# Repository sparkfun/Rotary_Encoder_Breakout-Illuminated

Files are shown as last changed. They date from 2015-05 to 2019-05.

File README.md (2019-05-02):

SparkFun Rotary Encoder Breakout - Illuminated (RG/RGB)
=======================================================

SparkFun Rotary Encoder Breakout - Illuminated (RG/RGB)

[*SparkFun Rotary Encoder Breakout - Illuminated (RG/RGB) (BOB-11722)*](https://www.sparkfun.com/products/11722)

This is a clever little breakout board for both the RGB and R/G illuminated rotary encoders. 
On one side, it breaks out all of the RGB pins to standard, breadboard friendly, 0.1" headers. 
Turn it over and it has a footprint for the R/G version! 

Repository Contents
-------------------
* **/Firmware** - Example for the RGB and RG Rotary Encoders
* **/Hardware** - Eagle design files (.brd, .sch)
* **/Libraries** - Archived library of the PinChangeInt used for the example code

Documentation
--------------
* **[Installing an Arduino Library Guide](https://learn.sparkfun.com/tutorials/installing-an-arduino-library/all#manually-installing-a-library---windows)** - Basic information on how to install an Arduino library. You will need to manually install the PinChangeInt Arduino library.
* **[SparkFun Fritzing repo](https://github.com/sparkfun/Fritzing_Parts)** - Fritzing diagrams for SparkFun products.
* **[SparkFun 3D Model repo](https://github.com/sparkfun/3D_Models)** - 3D models of SparkFun products. 

Product Versions
----------------

Compatible with the following rotary encoders: 

* [COM-15141](https://www.sparkfun.com/products/15141) - RGB rotary encoder - illuminated; buttons and LEDs are common cathode
* [COM-15140](https://www.sparkfun.com/products/15140) - RG rotary encoder - illuminated, buttons and LEDs are common anode
* _[COM-10982 (retired)](https://www.sparkfun.com/products/10982) - RGB rotary encoder - illuminated; buttons and LEDs are common cathode_
* _[COM-10596 (retired)](https://www.sparkfun.com/products/10596) - RG rotary encoder - illuminated, buttons and LEDs are common anode_

License Information
-------------------
This product is _**open source**_! 

The **hardware** is released under [Creative Commons ShareAlike 4.0 International](https://creativecommons.org/licenses/by-sa/4.0/).

Please use, reuse, and modify these files as you see fit. Please maintain attribution to SparkFun Electronics and release anything derivative under the same license.

Distributed as-is; no warranty is given.

- Your friends at SparkFun.

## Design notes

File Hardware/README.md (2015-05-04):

SparkFun <PRODUCT NAME> Design Files
=====================================

The .sch and .brd files hare are Eagle CAD schematic and PCB design files from SparkFun Electronics.
A freeware version of Eagle can be found [here](http://www.cadsoftusa.com/download-eagle/freeware/). 

License
---------
This product is open source! 
The hardware is released under [Creative Commons ShareAlike 4.0 International](https://creativecommons.org/licenses/by-sa/4.0/).

Please use, reuse, and modify these files as you see fit. Please maintain attribution to SparkFun Electronics and release anything derivative under the same license.

Distributed as-is; no warranty is given.

- Your friends at SparkFun.

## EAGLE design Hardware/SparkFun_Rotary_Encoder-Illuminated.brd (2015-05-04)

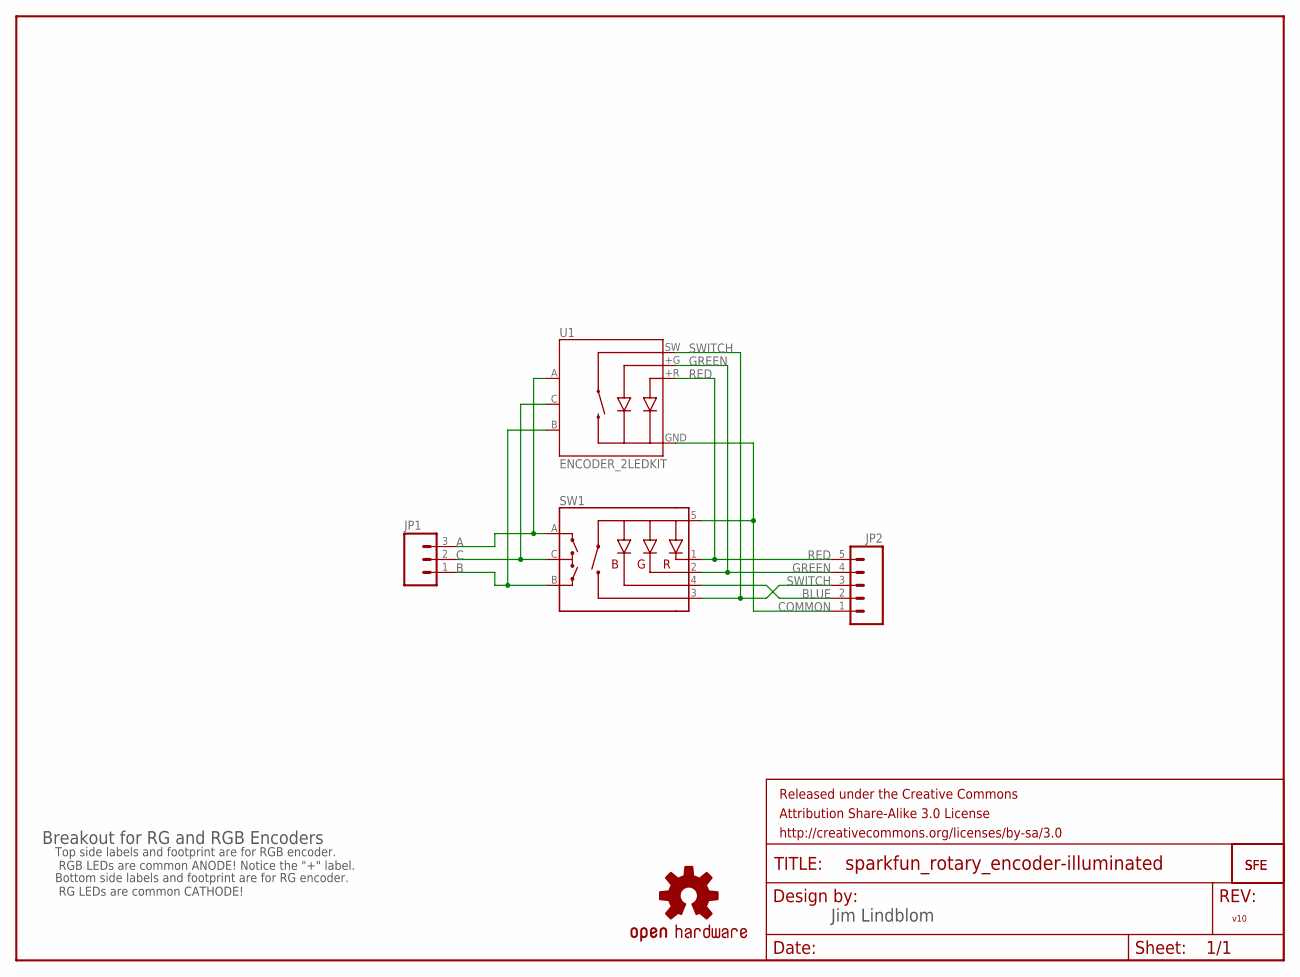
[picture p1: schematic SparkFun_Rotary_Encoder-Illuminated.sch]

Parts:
FRAME1: FRAME-LETTER; CREATIVE_COMMONS
JP1: M03PTH; 1X03
JP2: M05PTH; 1X05
JP3, JP4: LOGO-SFESK; SFE-LOGO-FLAME
SW1: ENCODER_RGB_CAKIT; ENCODER_LED_3_KIT
U1: ENCODER_2LEDKIT; ENCODER_LED_2_KIT
U$2: OSHW-LOGOS; OSHW-LOGO-S

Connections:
A: JP1.3, SW1.A, U1.A
B: JP1.1, SW1.B, U1.B
BLUE: JP2.2, SW1.4 (-B)
C: JP1.2, SW1.C, U1.C
COMMON: JP2.1, SW1.5 (+), U1.GND (-)
GREEN: JP2.4, SW1.2 (-G), U1.+G
RED: JP2.5, SW1.1 (-R), U1.+R
SWITCH: JP2.3, SW1.3 (SW), U1.SW

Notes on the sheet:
Jim Lindblom
Breakout for RG and RGB Encoders
Top side labels and footprint are for RGB encoder. RGB LEDs are common ANODE! Notice the "+" label.
Bottom side labels and footprint are for RG encoder. RG LEDs are common CATHODE!
v10

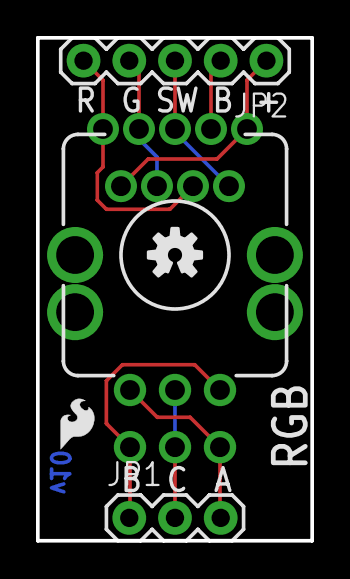
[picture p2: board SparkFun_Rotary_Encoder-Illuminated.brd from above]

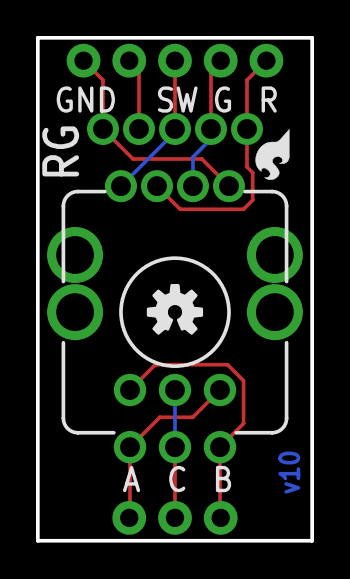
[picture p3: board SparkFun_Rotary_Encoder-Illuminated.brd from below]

Board: 2 copper layers, 15.2 x 27.9 mm, 9 parts (3 on the bottom side), 8 nets.

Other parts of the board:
U$1: OSHW-LOGOS; OSHW-LOGO-S

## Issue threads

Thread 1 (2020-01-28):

Rotary encoder demo code

NLoebel, 2020-01-28:
1.  Code uses syntax:   attachInterrupt(1, rotaryIRQ, CHANGE);

from https://www.arduino.cc/reference/en/language/functions/external-interrupts/attachinterrupt/ this doesn't necessarily work for different boards:

attachInterrupt(digitalPinToInterrupt(pin), ISR, mode) (recommended)
attachInterrupt(interrupt, ISR, mode) (not recommended)
attachInterrupt(pin, ISR, mode) (Not recommended. Additionally, this syntax only works on Arduino SAMD Boards, Uno WiFi Rev2, Due, and 101.)

2. Code uses:   attachInterrupt(1, rotaryIRQ, CHANGE);

although the code works as written (??), Pin 1 is not used in the sketch.  The rotary encoder is wired as:
(// Rotary encoder pin A to digital pin 3*     * Pins marked with an asterisk should not change
// Rotary encoder pin B to analog pin 3
// Rotary encoder pin C to ground

...so how this works attaching the interrupt to the wrong pin, I dunno.

3. Code states to attach LEDs directly to GPIO ports:

// Rotary encoder pin 1 (red anode) to digital pin 10
// Rotary encoder pin 2 (green anode) to analog pin 1
// Rotary encoder pin 3 (button) to digital pin 4

they should be attached through series dropping resistors to avoid high intensity one-shot flashes.

4. Code sets input pullups using deprecated syntax used prior to Arduino 1.0.1:

digitalWrite(ROT_A, HIGH); // turn on weak pullup

this should be replaced with pinMode(pin, INPUT_PULLUP); where pin is ROT_A, ROT_B

iceananas, 2020-02-21:
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

Both issues are related.
I agree about 1, this code is pretty old and still uses the old Arduino convention.

About 2. and why this code works, you find the answer in your own link:

> However, older sketches often have direct interrupt numbers. Often number 0 (for digital pin 2) or number 1 (for digital pin 3) were used.

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

Agree. This code could be updated.

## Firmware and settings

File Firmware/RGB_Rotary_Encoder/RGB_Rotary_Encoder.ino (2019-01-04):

// "RGB_Rotary_Encoder"
// Example sketch based on the Lilypad MP3 Player
// but modified for the the Arduino Uno/RedBoard
// Modified By: Ho Yun Bobby Chan
// By: Mike Grusin, SparkFun Electronics
// http://www.sparkfun.com

// This sketch demonstrates (only) the use of the rotary encoder
// hardware on the Lilypad MP3 Player board from Sparkfun. If you
// want to use the rotary encoder in your own sketches, this code
// will give you a starting point.

// HARDWARE CONNECTIONS

// This sketch will run on a LilyPad MP3 Player board (with
// a rotary encoder installed) without modifications.

// If you're not using the LilyPad MP3 Player board, connect
// a rotary encoder to your Arduino using these pins:

// Rotary encoder pin A to digital pin 3*
// Rotary encoder pin B to analog pin 3
// Rotary encoder pin C to ground

// This sketch implements software debounce, but you can further
// improve performance by placing 0.1uF capacitors between
// A and ground, and B and ground.

// If you wish to use the RGB LED and button functions of
// SparkFun part number COM-10982, use the following connections:

// Rotary encoder pin 1 (red cathode) to digital pin 10
// Rotary encoder pin 2 (green cathode) to analog pin 1
// Rotary encoder pin 3 (button) to digital pin 4
// Rotary encoder pin 4 (blue cathode) to digital pin 5
// Rotary encoder pin 5 (common anode) to VCC (3.3V or 5V)

// Note that because this is a common anode device,
// the pushbutton requires an external 1K-10K pullDOWN resistor
// to operate.

// * Pins marked with an asterisk should not change because
// they use interrupts on that pin. All other pins can change,
// see the constants below.

// SERIAL MONITOR

// Run this sketch with the serial monitor window set to 9600 baud.

// HOW IT WORKS

// The I/O pins used by the rotary encoder hardware are set up to
// automatically call interrupt functions (rotaryIRQ and buttonIRQ)
// each time the rotary encoder changes states.

// The rotaryIRQ function transparently maintains a counter that
// increments or decrements by one for each detent ("click") of
// the rotary encoder knob. This function also sets a flag
// (rotary_change) to true whenever the counter changes. You can
// check this flag in your main loop() code and perform an action
// when the knob is turned.

// The buttonIRQ function does the same thing for the pushbutton
// built into the rotary encoder knob. It will set flags for
// button_pressed and button_released that you can monitor in your
// main loop() code. There is also a variable for button_downtime
// which records how long the button was held down.

// There is also code in the main loop() that keeps track
// of whether the button is currently being held down and for
// how long. This is useful for "hold button down for five seconds
// to power off"-type situations, which cannot be handled by
// interrupts alone because no interrupts will be called until
// the button is actually released.

// Uses the PinChangeInt library by Lex Talionis,
// download from http://code.google.com/p/arduino-pinchangeint/

// License:
// We use the "beerware" license for our firmware. You can do
// ANYTHING you want with this code. If you like it, and we meet
// someday, you can, but are under no obligation to, buy me a
// (root) beer in return.

// Have fun!
// -your friends at SparkFun

// Revision history:
// 1.0 initial release MDG 2013/01/24

// Load the PinChangeInt (pin change interrupt) library

#include <PinChangeInt.h>

// LilyPad MP3 pin defines. Not all of these are used in this
// sketch; the unused pins are commented out:

#define ROT_LEDG A1     // green LED
#define ROT_B A3        // rotary B
#define ROT_A 3          // rotary A
#define ROT_SW 4         // rotary puhbutton
#define ROT_LEDB 5       // blue LED
#define ROT_LEDR 10      // red LED

// RGB LED colors (for common anode LED, 0 is on, 1 is off)
#define OFF B111
#define RED B110
#define GREEN B101
#define YELLOW B100
#define BLUE B011
#define PURPLE B010
#define CYAN B001
#define WHITE B000

// Global variables that can be changed in interrupt routines
volatile int rotary_counter = 0; // current "position" of rotary encoder (increments CW)
volatile boolean rotary_change = false; // will turn true if rotary_counter has changed
volatile boolean button_pressed = false; // will turn true if the button has been pushed
volatile boolean button_released = false; // will turn true if the button has been released (sets button_downtime)
volatile unsigned long button_downtime = 0L; // ms the button was pushed before release

// "Static" variables are initalized once the first time
// that loop runs, but they keep their values through
// successive loops.

static unsigned char x = 0; //LED color
static boolean button_down = false;
static unsigned long int button_down_start, button_down_time;

void setup()
{
  // Set up all the I/O pins. Unused pins are commented out.
  pinMode(ROT_B, INPUT);
  digitalWrite(ROT_B, HIGH); // turn on weak pullup
  pinMode(ROT_A, INPUT);
  digitalWrite(ROT_A, HIGH); // turn on weak pullup
  pinMode(ROT_SW, INPUT);
  // The rotary switch is common anode with external pulldown, do not turn on pullup
  pinMode(ROT_LEDB, OUTPUT);
  pinMode(ROT_LEDG, OUTPUT);
  pinMode(ROT_LEDR, OUTPUT);

  setLED(WHITE);

  Serial.begin(9600); // Use serial for debugging
  Serial.println("Begin RGB Rotary Encoder Testing");

  // We use the standard external interrupt pin for the rotary,
  // but we'll use the pin change interrupt library for the button.

  attachInterrupt(1, rotaryIRQ, CHANGE);
  PCintPort::attachInterrupt(ROT_SW, &buttonIRQ, CHANGE);
}

void buttonIRQ()
{
  // Process rotary encoder button presses and releases, including
  // debouncing (extra "presses" from noisy switch contacts).
  // If button is pressed, the button_pressed flag is set to true.
  // (Manually set this to false after handling the change.)
  // If button is released, the button_released flag is set to true,
  // and button_downtime will contain the duration of the button
  // press in ms. (Set this to false after handling the change.)

  // Raw information from PinChangeInt library:

  // Serial.print("pin: ");
  // Serial.print(PCintPort::arduinoPin);
  // Serial.print(" state: ");
  // Serial.println(PCintPort::pinState);

  static boolean button_state = false;
  static unsigned long start, end;

  if ((PCintPort::pinState == HIGH) && (button_state == false))
    // Button was up, but is currently being pressed down
  {
    // Discard button presses too close together (debounce)
    start = millis();
    if (start > (end + 10)) // 10ms debounce timer
    {
      button_state = true;
      button_pressed = true;
    }
  }
  else if ((PCintPort::pinState == LOW) && (button_state == true))
    // Button was down, but has just been released
  {
    // Discard button releases too close together (debounce)
    end = millis();
    if (end > (start + 10)) // 10ms debounce timer
    {
      button_state = false;
      button_released = true;
      button_downtime = end - start;
    }
  }
}


void rotaryIRQ()
{
  // Process input from the rotary encoder.
  // The rotary "position" is held in rotary_counter, increasing for CW rotation (changes by one per detent).
  // If the position changes, rotary_change will be set true. (You may manually set this to false after handling the change).

  // This function will automatically run when rotary encoder input A transitions in either direction (low to high or high to low)
  // By saving the state of the A and B pins through two interrupts, we'll determine the direction of rotation
  // int rotary_counter will be updated with the new value, and boolean rotary_change will be true if there was a value change
  // Based on concepts from Oleg at circuits@home (http://www.circuitsathome.com/mcu/rotary-encoder-interrupt-service-routine-for-avr-micros)
  // Unlike Oleg's original code, this code uses only one interrupt and has only two transition states;
  // it has less resolution but needs only one interrupt, is very smooth, and handles switchbounce well.

  static unsigned char rotary_state = 0; // current and previous encoder states

  rotary_state <<= 2;  // remember previous state
  rotary_state |= (digitalRead(ROT_A) | (digitalRead(ROT_B) << 1));  // mask in current state
  rotary_state &= 0x0F; // zero upper nybble

  //Serial.println(rotary_state,HEX);

  if (rotary_state == 0x09) // from 10 to 01, increment counter. Also try 0x06 if unreliable
  {
    rotary_counter++;
    rotary_change = true;
  }
  else if (rotary_state == 0x03) // from 00 to 11, decrement counter. Also try 0x0C if unreliable
  {
    rotary_counter--;
    rotary_change = true;
  }
}


void loop()
{
  // The rotary IRQ sets the flag rotary_counter to true
  // if the knob position has changed. We can use this flag
  // to do something in the main loop() each time there's
  // a change. We'll clear this flag when we're done, so
  // that we'll only do this if() once for each change.

  if (rotary_change)
  {
    Serial.print("rotary: ");
    Serial.println(rotary_counter, DEC);
    rotary_change = false; // Clear flag

    //blink for visual feedback
    setLED(OFF);
    delay(10); //try not to make this too long, otherwise the Arduino will miss ticks
    setLED(x);
  }

  // The button IRQ also sets flags to true, one for
  // button_pressed, one for button_released. Like the rotary
  // flag, we'll clear these when we're done handling them.

  if (button_pressed)
  {
    Serial.println("button press");
    //x++; setLED(x); // Change the color of the knob LED
    button_pressed = false; // Clear flag

    // We'll set another flag saying the button is now down
    // this is so we can keep track of how long the button
    // is being held down. (We can't do this in interrupts,
    // because the button state is not changing).

    button_down = true;
    button_down_start = millis();
  }

  if (button_released)
  {
    Serial.print("button release, downtime: ");
    Serial.println(button_downtime, DEC);
    x++; setLED(x); // Change the color of the knob LED
    button_released = false; // Clear flag

    // Clear our button-being-held-down flag
    button_down = false;

    //blink when you release the button press
    for (int i = 0; i < 4; i++) {
      digitalWrite(ROT_LEDR, LOW);
      digitalWrite(ROT_LEDG, HIGH);
      digitalWrite(ROT_LEDB, HIGH);
      delay(50);
      digitalWrite(ROT_LEDR, HIGH);
      digitalWrite(ROT_LEDG, HIGH);
      digitalWrite(ROT_LEDB, HIGH);
      delay(50);
    }

    setLED(x); // Change the color back to original color
  }

  // Now we can keep track of how long the button is being
  // held down, and perform actions based on that time.
  // This is useful for "hold down for five seconds to power off"
  // -type functions.

  if (button_down)
  {
    button_down_time = millis() - button_down_start;
    // Serial.println(button_down_time);
    if (button_down_time > 1000) {
      Serial.println("button held down for one second");
    }
    //if LED is pressed down, display red
    digitalWrite(ROT_LEDR, LOW);
    digitalWrite(ROT_LEDG, HIGH);
    digitalWrite(ROT_LEDB, HIGH);

  }
}


void setLED(unsigned char color)
// Set RGB LED to one of eight colors (see #defines above)
{
  digitalWrite(ROT_LEDR, color & B001);
  digitalWrite(ROT_LEDG, color & B010);
  digitalWrite(ROT_LEDB, color & B100);
}

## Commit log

2015-05-04 Adding README info, updating product files
    [SparkFun_Rotary_Encoder-Illuminated.brd, SparkFun_Rotary_Encoder-Illuminated.sch]
2018-12-20 Example Code for RGB Rotary Encoder
    Add example code for the RGB Rotary Encoder
    Add library used with example code.
2018-12-20 Turn LED to White on Start
2019-01-04 Create RG_Rotary_Encoder_Demo.ino
    Logic is reversed in this version of code since the RG Rotary Switch is a common anode instead of common cathode. Blue is commented out since it is not being used. The switch will be using a pullUP resistor.
    [RG_Rotary_Encoder_Demo.ino]
2019-01-04 Moving RG Rotary Encoder Demo into Firmware Folder

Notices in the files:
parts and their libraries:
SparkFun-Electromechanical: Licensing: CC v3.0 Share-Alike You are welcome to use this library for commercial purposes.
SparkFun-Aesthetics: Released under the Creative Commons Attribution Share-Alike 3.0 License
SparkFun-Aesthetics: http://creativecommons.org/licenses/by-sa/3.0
